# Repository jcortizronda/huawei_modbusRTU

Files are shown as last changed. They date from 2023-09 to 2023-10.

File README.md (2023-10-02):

<a href='https://ko-fi.com/jcortizronda' target='_blank'>Buy Me a Coffee at ko-fi.com
Support via PayPal (https://www.paypal.me/jcortizronda/)

# huawei_modbusRTU
ModbusRTU Interface for Huawei Solar Inverters

This is a custom design of a pcb for MODBUS bus reading for Huawei inverters or similar. It includes an ESP32S3-MINI-N4 microcontroller and allows the reading of the RS485 bus thanks to an integrated converter. Unlike other existing integrations, this one allows you to have your inverter connected through ESPHome, fully configurable by the user.

I have hand-soldered my unit, so it's possible to do it!

The benefits of this integration are:
* Power the modbusRTU interface directly from your AC panel
* Calculating electricity cost and compensation for spanish billing system
* Translate fault and state codes to the corresponding strings
* Getting the home power and current consumptions
* Add a nice tesla-style-solar-power-card to your front-end
* Doing some basic monitoring of the solar yield of each of your strings (string ratio)
* Get notified when something goes wrong in your inverter

You can see images of real product in [images](images/) folder

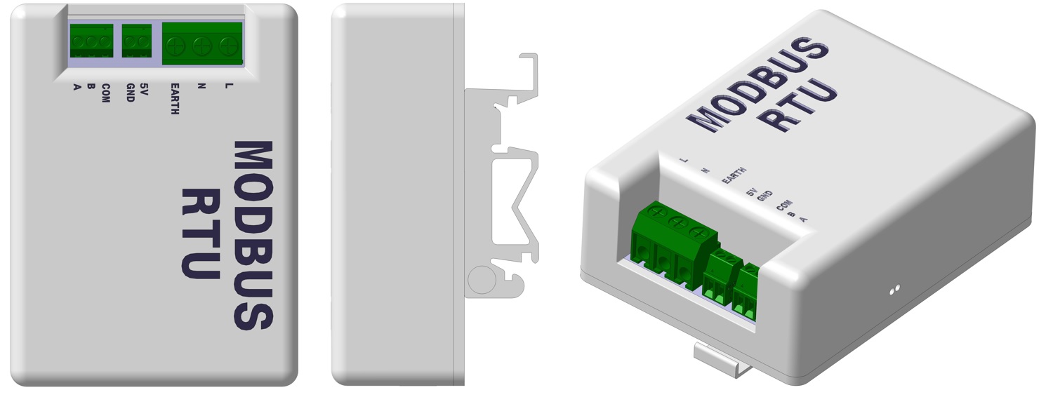
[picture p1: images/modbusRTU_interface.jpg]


# PCB

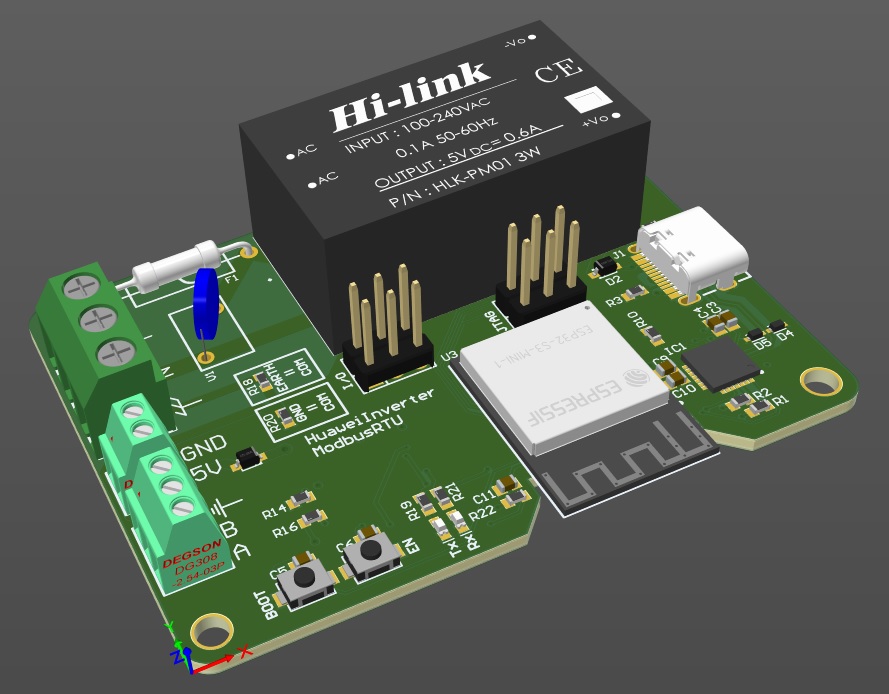
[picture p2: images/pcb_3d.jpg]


Includes the following: 

* ESP32-S3mini N8
* RS485 to TTL Converter
* AC/DC Module
* AC Overvoltage and Overcurrent protection
* USB-C Programming Connector
* JTAG Connector
* Custom IO Connector

All files for manufacturing are included in pcb folder:
* [BOM-HuaweiInverterMODBUS](manufacturing/PCB/BOM-HuaweiInverterMODBUS.xlsx)
* [PickPlace-HuaweiInverterMODBUS](manufacturing/PCB/PickPlace-HuaweiInverterMODBUS.csv)
* [Gerbers&NCDrills](manufacturing/PCB/Gerbers&NCDrills.zip)

ATTENTION! The PCB has two jumper resistors to select the COM connection of the RS485 port (Ground or Earth). I recommend to solder [GND = COM].

SOLDER ONLY ONE

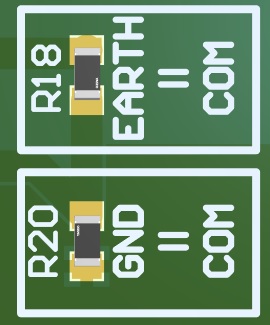
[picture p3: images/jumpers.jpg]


# Mounting

You will need the following elements:

1) PCB ModbusRTU Interface soldered
2) 3D Enclosure (modbusPCB_Part_A, modbusPCB_Part_B and din_clip)
3) 4x Screws M3x12 (for enclosure mounting)
4) 4x Screws M3x6 (for din clip mounting)

# Wiring

You have two options for powering ModbusRTU interface
* Connect L and N to your AC
* Connect 5V and GND to a 5V DC Adapter

Then, you must connect
1. Connect the A modbusRTU interface to your inverter's COM port (Pin 1)
2. Connect the A modbusRTU interface to your inverter's COM port (Pin 2)
3. Connect the GROUND modbusRTU interface to your interver's COM port (Pin 5)

 If using shielded cable, connect only one side to GROUND.

 Note: Inverter's COM port pin number are visible in the in the port itself.

WARNING: I recommend turning off the inverter through the switch, and the protections of the electrical panel that feed the inverter before making any connection.

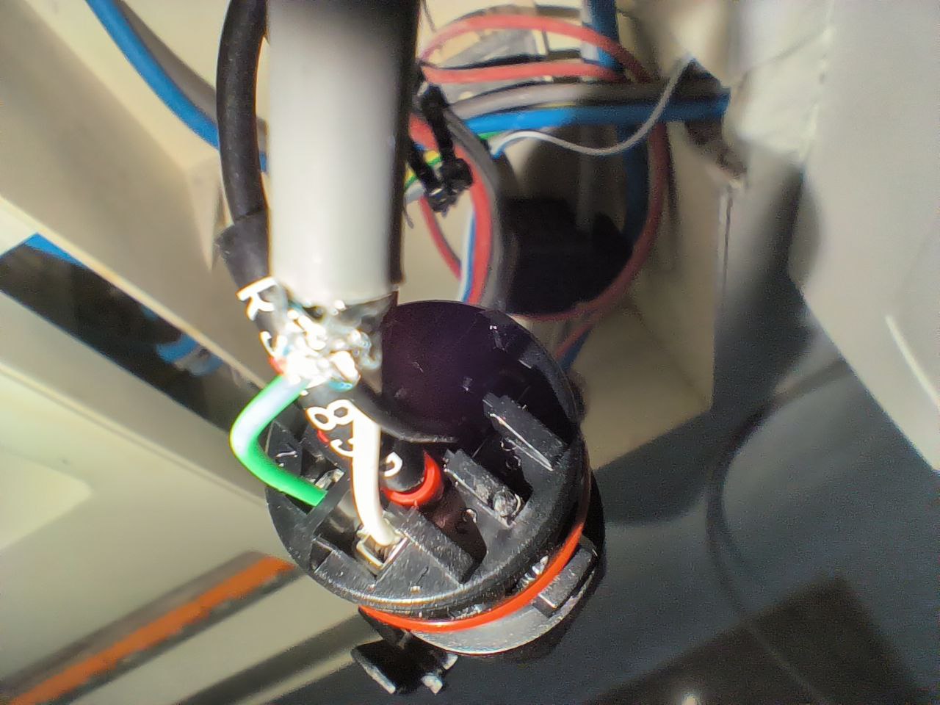
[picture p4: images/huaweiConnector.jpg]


# Setup
1. Config [huawei-inverter.yaml](scripts/huawei-inverter.yaml) with your parameters.
2. Connect USB-C to modbusRTU interface and flash the file.
3. Make the connections previously explained.
4. Connect ESPHome device to HomeAssistant and add ESPHome device.
Home Assistant should discover the new device.

### Configuration part in huawei-inverter.yaml
```yml
# Enable Home Assistant API
api:
  encryption:
    key: !secret huawei-inverter-encryption

ota:
  password: !secret huawei-inverter-ota

wifi:
  ssid: !secret wifi_ssid
  password: !secret wifi_password

  # Enable fallback hotspot (captive portal) in case wifi connection fails
  ap:
    ssid: "Huawei-Inverter Fallback Hotspot"
    password: !secret huawei-inverter-fallback
```

### HomeAssistant Card and information

You will get all the information that your inverter provides through the COM port, and you will be able to configure it to your liking.

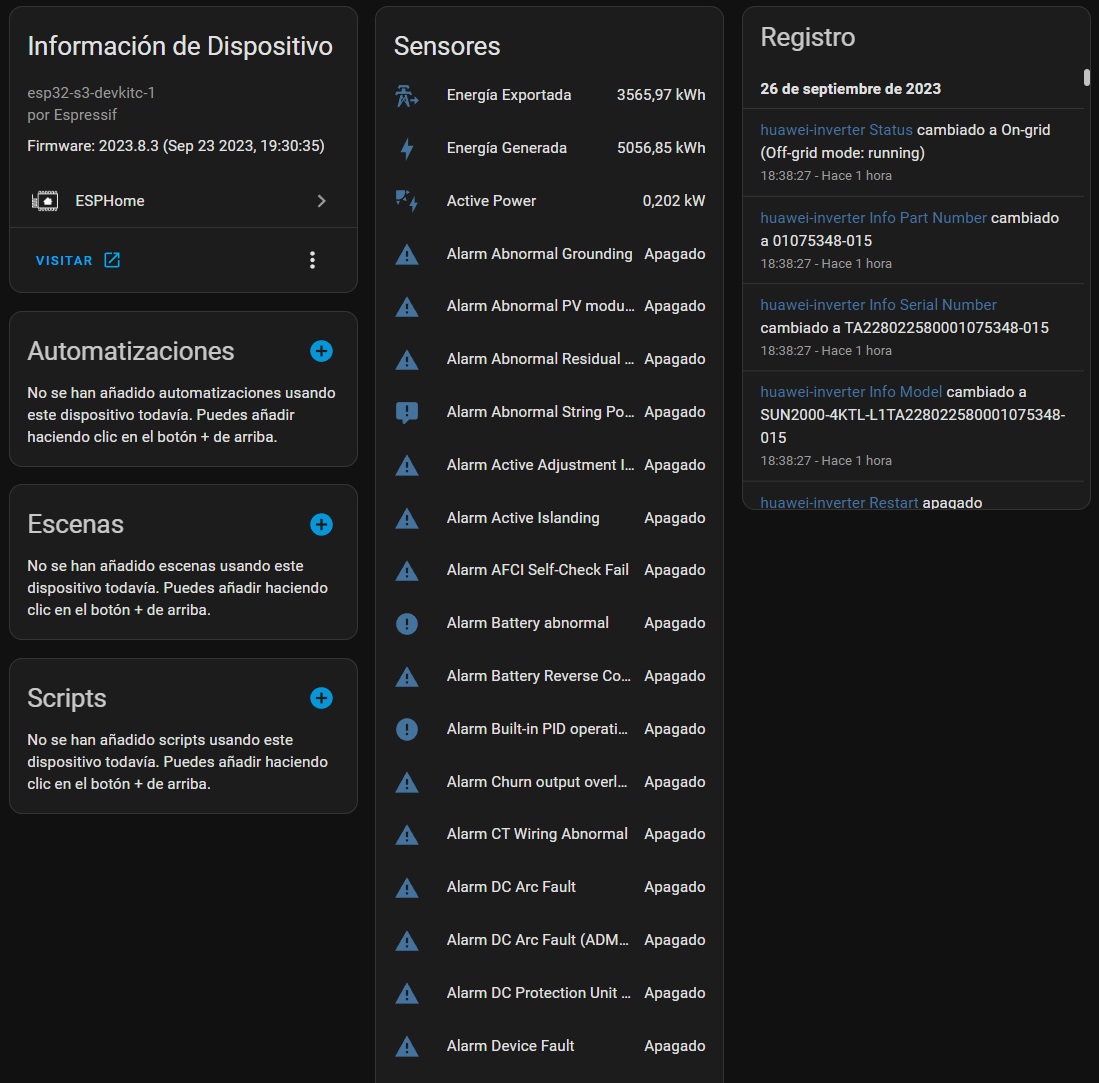
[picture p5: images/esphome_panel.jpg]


You can use the [tesla-solar-card](https://github.com/reptilex/tesla-style-solar-power-card) to see in real time the energy flow of your home.

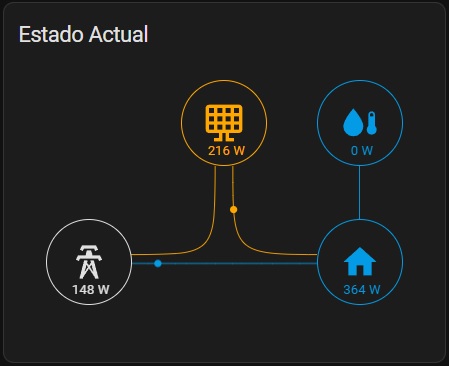
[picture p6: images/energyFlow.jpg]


# Acknowledgments

Thanks to jesusrop for his work in his [repository](https://github.com/jesusrop/esphome_huawei_sun2000), on which I have based my work.

### Wanna a Plug&Play ModbusRTU Converter? Write me and I will do my best to send you one at the best price.

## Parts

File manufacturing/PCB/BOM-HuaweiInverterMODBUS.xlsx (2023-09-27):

Line # | Name | Description | Designator | Quantity | Value | Manufacturer | MPN | Supplier 1 | Supplier Part Number 1 | Supplier Unit Price 1 | Supplier Subtotal 1
 | HLK-PM01 | 3W Ultra-compact power module In: 100-240Vac Out: 5Vdc 0.6A | B1 | 1
 | AMS1117-3.3 | 1A 3.3VDC LOW DROPOUT VOLTAGE REGULATOR, SOT-223 | B2 | 1
 | CL10A226MP8NUNE | Condensadores de cerámica multicapa (MLCC- SMD/SMT) 22uF+/-20% 10V X5R 0603 | C1, C2 | 2 | 22uF
 | CAP_0603_0.1UF_20%_50V_X5R | Condensadores de cerámica multicapa (MLCC- SMD/SMT) 0.1uF+/-20% 50V X5R 0603 | C3, C5, C6, C7, C9, C11 | 6 | 0.1uF
 | CAP_0603_4.7UF_20%_10V_X5R | Condensadores de cerámica multicapa (MLCC- SMD/SMT) 4.7uF+/-20% 10V X5R 0603 | C4 | 1 | 4.7uF
 | CAP_0603_100pF_5%_50V_C0G | Condensadores de cerámica multicapa (MLCC- SMD/SMT) 0.1uF+/-5% 50V C0G 0603 | C8 | 1 | 100pF
 | CAP0603_22UF_20%_10V_X5R | Condensadores de cerámica multicapa (MLCC- SMD/SMT) 22uF+/-20% 10V X5R 0603 | C10 | 1 | 22uF
 | CDSOD323-T05SC | 14.5V 6V 5V SOD-323 TVS ROHS | D1, D8, D9 | 3 |  | BOURNS | CDSOD323-T05SC
 | BAT760-7 | 30V 550mV@1A 1A SOD-323 Schottky Barrier Diodes (SBD) ROHS | D2, D7 | 2 |  | Diodes Incorporated | BAT760-7
 | LESD5D5.0CT1G | 5.6V 18.6V 5V Bi-Directional SOD-523 ESD Protection Devices ROHS | D3, D4, D5 | 3 |  | LRC | LESD5D5.0CT1G
 | 0603_LED_GREEN_1.8V | 0603 Green Led | D6, D12 | 2
 | 1N4148W T4 | Diode 100V 500mW Single 1.25V@150mA 4ns 150mA SOD-123 Switching Diode ROHS | D10 | 1 |  | CJ | 1N4148W
 | 0603_LED_RED_1.9V | 0603 Red Led | D11 | 1
 | FUSE_TH_1A_GLASS | Fuse 1A AC250V | F1 | 1 | 1A | Hongda | 31FC1A250V
 | MF-MSMF010-2 | Resettable Fuses 60V 100mA 40A 300mA 1812 Resettable Fuses ROHS | F2, F3 | 2 |  | BOURNS | MF-MSMF010-2
 | CP2102N-A02-GQFN28 | CI de interfaz USB USBXpress - USB to UART Bridge QFN28 | IC1 | 1
 | USB-C | 3A Surface Mount 16P Female -25℃~+85℃ Type-C SMD USB Connectors ROHS | J1 | 1 |  | Dealon | USB-TYPE-C-018
 | WJ126V-5.0-3P | 1x3P 18A -40℃~+105℃ 250V Green 14~26 Straight pin 5mm 2.5 1 3 Plugin,P=5mm Screw terminal ROHS | J2 | 1 |  | KANGNEX | WJ126V-5.0-3P
 | XY308-2.54-2P | 1x2P 6A 150V Green 18~26 Straight pin 2.54mm 1 1 2 Plugin,P=2.54mm Screw terminal ROHS | J3 | 1 |  | XINLAIYA | XY308-2.54-2P
 | XY308-2.54-3P | Screw Terminal 1x3P 6A 150V Green 18~26 Straight pin 2.54mm 1 1 3 Plugin,P=2.54mm ROHS | J4 | 1 |  | XINLAIYA | XY308-2.54-3P
 | Header-Male-2.54_2x3 | Pin Header Straight 6P 2.54mm Black Plugin,P=2.54mm Pin Headers ROHS | J5, J6 | 2 |  | BOOMELE | 2.54-2*3P针
 | SS8050-G | 25V 300mW 120@100mA,1V 1.5A NPN SOT-23 Bipolar Transistors - BJT ROHS | Q1, Q2 | 2 |  | Jiangsu Changjing Electronics Technology | SS8050-G
 | RES_0603_22OHM_0.1W | Res Thick Film 0603 22 Ohm 1% 0.1W(1/10W) +/-100ppm/C Epoxy Pad SMD T/R | R1, R2, R23, R24 | 4 | 22Ω | Yageo | RT0603FRE075K1L
 | RES_0603_5.1KOHM_0.1W | Res Thick Film 0603 5.1K Ohm 1% 0.1W(1/10W) +/-100ppm/C Epoxy Pad SMD T/R | R3, R4 | 2 | 5.1kΩ | Yageo | RT0603FRE075K1L
 | RES_0603_1KOHM_0.1W | Res Thick Film 0603 1K Ohm 1% 0.1W(1/10W) +/-100ppm/C Epoxy Pad SMD T/R | R5, R11 | 2 | 1kΩ | Yageo | RC0603FR-071KL
 | RES_0603_10KOHM_0.1W | Res Thick Film 0603 10K Ohm 1% 0.1W(1/10W) +/-100ppm/C Epoxy Pad SMD T/R | R6, R8, R10, R22 | 4 | 10kΩ | Yageo | RT0603FRE075K1L
 | RES_0603_22.1KOHM_0.1W | Res Thick Film 0603 22.1K Ohm 1% 0.1W(1/10W) +/-100ppm/C Epoxy Pad SMD T/R | R7 | 1 | 22.1kΩ | Yageo | RT0603FRE075K1L
 | RES_0603_47.5KOHM_0.1W | Res Thick Film 0603 47.5K Ohm 1% 0.1W(1/10W) +/-100ppm/C Epoxy Pad SMD T/R | R9 | 1 | 47.5kΩ | Yageo | RT0603FRE075K1L
 | RES_0603_4.7KOHM_0.1W | Res Thick Film 0603 4.7K Ohm 1% 0.1W(1/10W) +/-100ppm/C Epoxy Pad SMD T/R | R12, R13, R14, R16 | 4 | 4.7kΩ | Yageo | RT0603FRE075K1L
 | RES_0603_120OHM_0.1W | Res Thick Film 0603 120 Ohm 1% 0.1W(1/10W) +/-100ppm/C Epoxy Pad SMD T/R | R15 | 1 | 120Ω | Yageo | RT0603FRE075K1L
 | RES_0603_56KOHM_0.1W | Res Thick Film 0603 56K Ohm 1% 0.1W(1/10W) +/-100ppm/C Epoxy Pad SMD T/R | R17 | 1 | 56kΩ | Yageo | RT0603FRE075K1L
 | RES_0603_0OHM_0.1W | Res Thick Film 0603 0 Ohm 1% 0.1W(1/10W) +/-100ppm/C Epoxy Pad SMD T/R | R18, R20 | 2 | 0Ω | Yageo | RT0603FRE075K1L
 | RES_0603_500OHM_0.1W | Res Thick Film 0603 500 Ohm 1% 0.1W(1/10W) +/-100ppm/C Epoxy Pad SMD T/R | R19, R21 | 2 | 500Ω | Yageo | RT0603FRE075K1L
 | HX TS342A2P WZ 250GF | SMD Tactile Switches ROHS | SW1, SW2 | 2 |  | Hanxia | HX TS342A2P WZ 250gf
 | CD4069UBM/TR | SOIC-14 Inverters ROHS | U1 | 1 |  | HGSEMI | CD4069UBM/TR
 | MAX485EAS | SOP-8 RS-485/RS-422 ICs ROHS | U2 | 1 |  | UMW | MAX485ESA
 | ESP32-S3-MINI-1-N4R2 | ESP32-S3 Mini SMD WiFi Modules ROHS | U3 | 1 |  | ESPRESSIF | ESP32-S3-MINI-1-N4R2
 | V275LA4P | Plugin Varistors 275Vrms ROHS | V1 | 1 |  | Littelfuse | V275LA4P

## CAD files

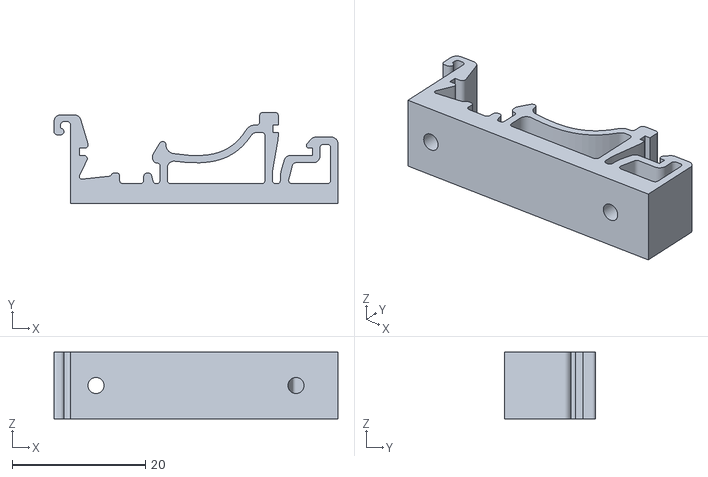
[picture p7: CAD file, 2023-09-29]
enclosure/din_clip.STL
42.6 x 13.7 x 10.0

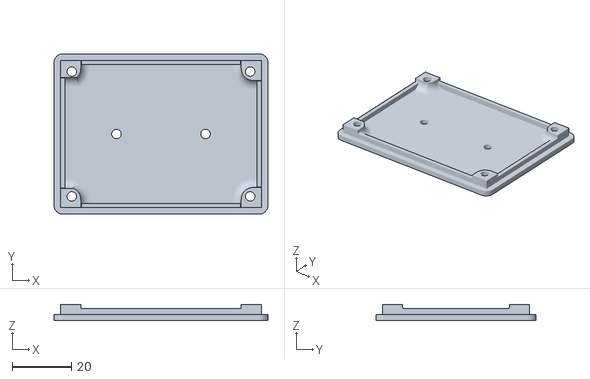
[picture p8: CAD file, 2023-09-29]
enclosure/modbusPCB_Part_B.stl
72.0 x 54.0 x 5.39

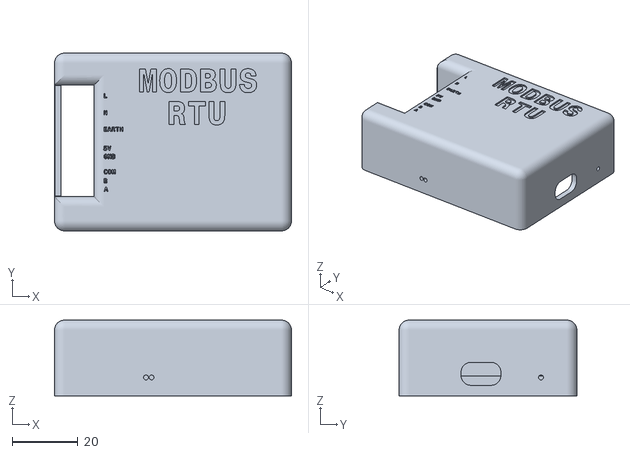
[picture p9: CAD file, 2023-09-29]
enclosure/modbusPCB_Part_A.stl
72.0 x 54.0 x 23.0

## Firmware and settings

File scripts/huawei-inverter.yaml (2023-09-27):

esphome:
  name: huawei-inverter
  friendly_name: huawei-inverter

esp32:
  board: esp32-s3-devkitc-1
  framework:
    type: arduino

# Enable logging
logger:

# Enable Home Assistant API
api:
  encryption:
    key: !secret huawei-inverter-encryption

ota:
  password: !secret huawei-inverter-ota

wifi:
  ssid: !secret wifi_ssid
  password: !secret wifi_password

  # Enable fallback hotspot (captive portal) in case wifi connection fails
  ap:
    ssid: "Huawei-Inverter Fallback Hotspot"
    password: !secret huawei-inverter-fallback

captive_portal:

switch:
  - platform: restart
    name: "Restart"

uart:
  id: mod_bus
  baud_rate: 9600
  tx_pin: GPIO17  # TX2
  rx_pin: GPIO18  # RX2
  rx_buffer_size: 1024
  data_bits: 8
  stop_bits: 1
  parity: NONE

modbus:
  id: modbus1

modbus_controller:
  - id: huawei_inverter
    address: 0x1
    modbus_id: modbus1
    setup_priority: -10
    command_throttle: 750ms
    update_interval: 15s

text_sensor:
  # Range 30000 - 30035
  - name: "Info Model"
    icon: "mdi:information"
    platform: modbus_controller
    modbus_controller_id: huawei_inverter
    register_type: holding
    address: 30000
    register_count: 15
    response_size: 30
    skip_updates: 200
  - name: "Info Serial Number"
    icon: "mdi:information"
    platform: modbus_controller
    modbus_controller_id: huawei_inverter
    register_type: holding
    address: 30015
    register_count: 10
    response_size: 20
    skip_updates: 200
  - name: "Info Part Number"
    icon: "mdi:information"
    platform: modbus_controller
    modbus_controller_id: huawei_inverter
    register_type: holding
    address: 30025
    register_count: 10
    response_size: 20
    skip_updates: 200

  # Inverter status string
  - name: "Status"
    platform: template
    id: inverter_status_string
    icon: "mdi:information"


binary_sensor:
  # Range 32000 - 32019 (1/2)
  # Register 32000
  - name: "State Standby"
    icon: "mdi:information"
    platform: modbus_controller
    modbus_controller_id: huawei_inverter
    register_type: holding
    address: 32000
    bitmask: 0x001
  - name: "State Grid-Connection"
    icon: "mdi:information"
    platform: modbus_controller
    modbus_controller_id: huawei_inverter
    register_type: holding
    address: 32000
    bitmask: 0x002
  - name: "State Grid-Connecttion normally"
    icon: "mdi:information"
    platform: modbus_controller
    modbus_controller_id: huawei_inverter
    register_type: holding
    address: 32000
    bitmask: 0x004
  - name: "State Grid-Connecttion with derating due to power rationing"
    icon: "mdi:information"
    platform: modbus_controller
    modbus_controller_id: huawei_inverter
    register_type: holding
    address: 32000
    bitmask: 0x008
  - name: "State Grid-Connecttion with derating due to internal causes of inverter"
    icon: "mdi:information"
    platform: modbus_controller
    modbus_controller_id: huawei_inverter
    register_type: holding
    address: 32000
    bitmask: 0x010
  - name: "State normal stop"
    icon: "mdi:information"
    platform: modbus_controller
    modbus_controller_id: huawei_inverter
    register_type: holding
    address: 32000
    bitmask: 0x020
  - name: "State stop due to faults"
    icon: "mdi:information"
    platform: modbus_controller
    modbus_controller_id: huawei_inverter
    register_type: holding
    address: 32000
    bitmask: 0x040
  - name: "State stop due to power rationing"
    icon: "mdi:information"
    platform: modbus_controller
    modbus_controller_id: huawei_inverter
    register_type: holding
    address: 32000
    bitmask: 0x080
  - name: "State shutdown"
    icon: "mdi:information"
    platform: modbus_controller
    modbus_controller_id: huawei_inverter
    register_type: holding
    address: 32000
    bitmask: 0x100
  - name: "State spot check"
    icon: "mdi:information"
    platform: modbus_controller
    modbus_controller_id: huawei_inverter
    register_type: holding
    address: 32000
    bitmask: 0x200
  # Register 32002
  - name: "State unlocked"
    icon: "mdi:information"
    platform: modbus_controller
    modbus_controller_id: huawei_inverter
    register_type: holding
    address: 32002
    bitmask: 0x1
  - name: "State PV connected"
    icon: "mdi:information"
    platform: modbus_controller
    modbus_controller_id: huawei_inverter
    register_type: holding
    address: 32002
    bitmask: 0x2
  - name: "State DSP data collection"
    icon: "mdi:information"
    platform: modbus_controller
    modbus_controller_id: huawei_inverter
    register_type: holding
    address: 32002
    bitmask: 0x4
  # Register 32003
  - name: "State off-grid"
    icon: "mdi:information"
    platform: modbus_controller
    modbus_controller_id: huawei_inverter
    register_type: holding
    address: 32003
    bitmask: 0x1
  - name: "State off-grid switch enable"
    icon: "mdi:information"
    platform: modbus_controller
    modbus_controller_id: huawei_inverter
    register_type: holding
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

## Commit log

2023-09-27 Initial release
    [BOM-HuaweiInverterMODBUS.xlsx, HuaweiInverterMODBUS.PrjPcb, PickPlace-HuaweiInverterMODBUS.csv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]
2023-09-29 fix: 3d enclosure
    [din_clip.STL, modbusPCB_Part_A.stl, modbusPCB_Part_B.stl]
2026-10-13 Update huawei-inverter.yaml
    Filter in energies, fixed data types and fixed home assistant deprecated
